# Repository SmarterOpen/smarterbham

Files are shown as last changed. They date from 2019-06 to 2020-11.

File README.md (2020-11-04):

# SmarterBham
The SmarterBham project
Imagine a city driven by information.  A place where decision making is supported by a city-wide sensor network that provides real time data about the state of things.  Imagine the platform that runs the network, built and owned by the citizens, measuring the things that we think are important and giving us the insights we need to make our city the best it can be. The SmarterBham project was born out of a recognition that smart cities need grassroots participation. We can combine open hardware designs with open networks, open platforms and open data policies to build a participatory smart cities future.

# Project Structure
* /lopy4 - all the code that runs on the device
* /doc - our documentation.  Requirements, wireframes, flow, security audits, etc
* /web - the web application that we use to manage devices, users, and to analyze collected data

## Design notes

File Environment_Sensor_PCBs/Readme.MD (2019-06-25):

Created in Eagle 9.4
zip files contain Gerber files formatted for OSHPARK or similar.
10 unit buy has BOM from Mouser for all the parts used.  
Dust sensor was $10 cheaper each unit at newark, even after shipping.. so shop around

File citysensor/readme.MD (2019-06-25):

The contents of this folder are hereby deprecated.  We abandoned using a Raspi Zero W and moved to Pycom LoPy4 instead
This branch never went further than building a prototype PCB.

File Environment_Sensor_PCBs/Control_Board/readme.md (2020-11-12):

This folder will house the Control Board design filse

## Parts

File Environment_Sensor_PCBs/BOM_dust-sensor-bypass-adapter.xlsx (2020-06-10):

Part | Value | Part Number | Device | Package | Library | Sheet
C1 | 100nF | CC0603KRX7R8BB104 | CAP_NP_0603 | SMD_0603 | daneagle_db8.0 | 1
C2 | 2.2uF | 1206B225K160CT | CAP_NP_1206 | SMD_1206 | daneagle_db8.0 | 1
CON1 | 53261-0471 | 53261-0471 | 53261-0471 | 53261-04 | con-molex | 1
SOM1a | hdr-1x14 | 801-87-014-53-001101 | 1x14 socket adapter wire wrap | PYCOM_LOPY4_PTH | daneagle_db8.0 | 1
SOM1b | hdr-1x14 | 801-87-014-53-001101 | 1x14 socket adapter wire wrap | PYCOM_LOPY4_PTH | daneagle_db8.0 | 1
U2 | MIC9409x | MIC94091YC6-TR | MIC9409X-MICREL-HIGH-SIDE-LOAD-SW_SC70(C6) | SC-70(C6) | daneagle_db8.0 | 1

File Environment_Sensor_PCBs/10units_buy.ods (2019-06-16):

Qty | Value | Device | Package | Parts | Description | MF | Mouser PN | OC_FARNELL | OC_NEWARK
7 | 0.1uF | CAP_NP_0402 | SMD_0402 | C1, C3, C7
1 | 0r | RESISTOR_0603 | SMD_0603 | R0X76
4 | 100nF | CAP_NP_0603 | SMD_0603 | C1, C2
5 | 10uF | CAP_POL_SMD_1206 | CAP_POL_1206 | C3
1 | 1k | RESISTOR_0603 | SMD_0603 | R5
2 | 1k7 | RESISTOR_0603 | SMD_0603 | R1, R2
2 | 1k8 | RESISTOR_0402 | SMD_0402 | R1, R2
1 | 22k1 | RESISTOR_0603 | SMD_0603 | R6 |  |  | 603-RC0603FR-0722K1L
1 | 22uf | CAP_NP_0603 | SMD_0603 | C1
2 | 270k | RESISTOR_0402 | SMD_0402 | R1, R8
1 | 2A | FUSE_CLIP_SMD_AUTO_MINI_LOWPROF | FUSE_SMD_AUTO_MINI_LOWPROF | F1 |  |  | 576-0891002.H
1 | Holder | FUSE_CLIP_SMD_AUTO_MINI_LOWPROF | FUSE_SMD_AUTO_MINI_LOWPROF | F1 |  |  | 534-3587
2 | 2k2 | RESISTOR_0402 | SMD_0402 | R2, R3
1 | 330r | RESISTOR_0603 | SMD_0603 | R4
1 | 4.7uf | CAP_NP_0603 | SMD_0603 | C9
4 | 47k | RESISTOR_0402 | SMD_0402 | R4, R5, R6, R7
1 | 47k | RESISTOR_ARRAY_4X | SMD_4X_0603 | RA1
1 | 47k5 | RESISTOR_0603 | SMD_0603 | R7 |  |  | 603-RC0603FR-0747K5L
2 | 4k7 | RESISTOR_0603 | SMD_0603 | R1, R2
7 | 53261-04 | 53261-04 | 53261-04 | IN, OUT | CONNECTOR | MOLEX | 538-53261-0471 | 1125374 | unknown
2 | 53398-05 | 53398-05 | 53398-05 | X3, X4 | CONNECTOR | MOLEX | 538-53261-0571 | 1125354 | unknown
3 | 90R | RESISTOR_0603 | SMD_0603 | R3, R8, R9
1 | BME680_GAS_AQ/BARO/TEMP/HUMID-I2C-SPI | BME680_GAS_AQ/BARO/TEMP/HUMID-I2C-SPI | BOSCH_LGA8 | U1
1 | CP2012N-A01-GQFN20R | CP2012N-A01-GQFN20R | QFN20 | U2 |  |  | 634-CP2102NA01GQFN20
5 | EVPAA | SWITCH_MOM_PANA_EVPAA_3.5X2.9 | EVPAA_SWITCH | SW1, SW2, SW3, SW4, SW5
1 | GUVA_C32SM | GUVA_C32SM_OLGA | 2X2.3OLGA | U2
1 | GUVb_C31SM | GUVA_C32SM_OLGA | 2X2.3OLGA | U3
2 | LED_SMD_0603 | LED_SMD_0603 | LED_SMD_0603 |  |  |  | 743-IN-S63AT5G
2 | LED_SMD_0603 | LED_SMD_0603 | LED_SMD_0603 | D1, D2, D3, D4 |  |  | 743-S63BTR
1 | LM2596S_MOD_5.5VOUT | LM2596S-BUCK_CVTR-MODULE | LM2596S_MODULE | MOD1
1 | NCP1117_SOT-223-4 | NCP1117_SOT-223-4 | SOT-223 | U1
1 | SI1151_AB00_DFN10 | SI1151_AB00_DFN10 | QFN10 | U1 |  |  | 634-SI1132-A10-GMR
1 | USB | USB | USB_MICRO_B_SMD_AMPHENOL | CON1 |  |  | 649-10118193-0001LF
1 | USB_ESD-TVS_NUF2101MT1G | USB_ESD-TVS_NUF2101MT1G | TSOP-6 | U3 |  |  | 863-NUF2101MT1G
1 | VEML6070_OPLGA | VEML6070_OPLGA | OPLGA-6 | U2
1 |  | P-RJLSE-4X381-01_AMPHENOL | P-RJLSE-4X381-01_AMPHENOL_SMD_RJ45 | CON2 |  |  | 523-RJLSE4138101
1 |  | PYCOM_LOPY4PTH | PYCOM_LOPY4_PTH | SOM1 |  |  | 365-LOPY4
2 |  |  | socket 1x14 loprofile | SOM1 |  |  | 517-929870-01-14-RA
1 |  | Wifi Antenna Kit | WIFI Antenna Kit |  |  |  | 474-WRL-14676
1 |  | hpma115s0 dust sensor |  | x3

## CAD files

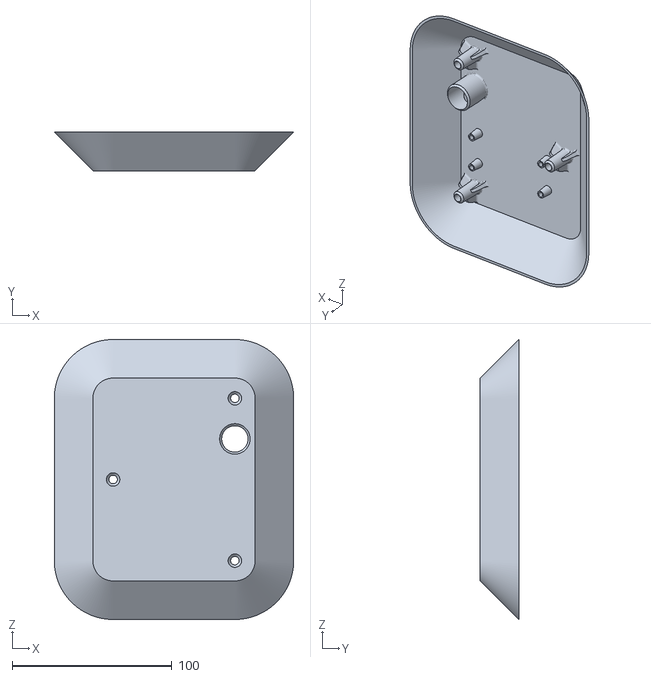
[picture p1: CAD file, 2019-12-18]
Environment_Sensor_PCBs/Louver_L4_v2.stl
149.9 x 24.1 x 175.3

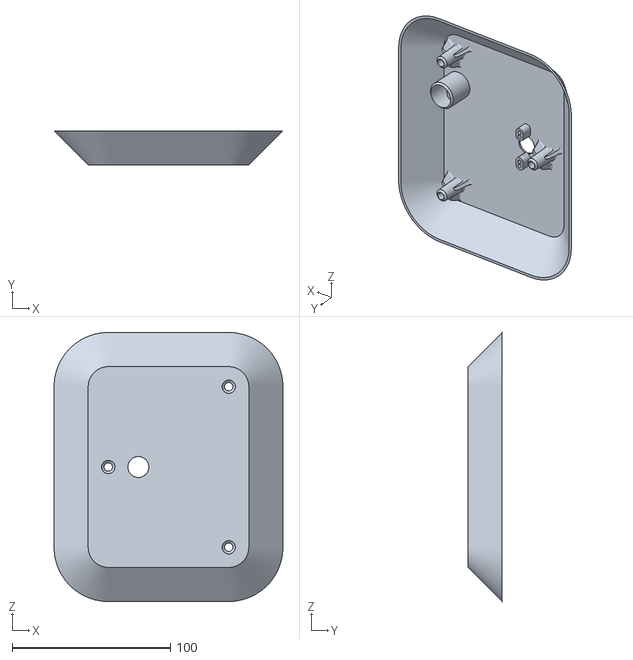
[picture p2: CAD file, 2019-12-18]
Environment_Sensor_PCBs/Louver_Top.v2.stl
144.8 x 21.6 x 170.2

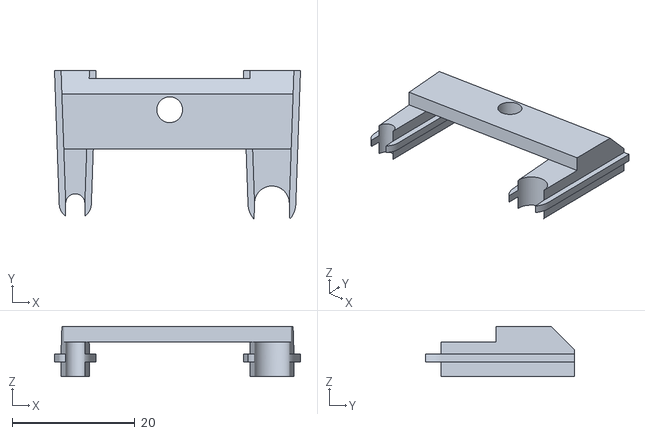
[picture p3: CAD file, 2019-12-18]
Environment_Sensor_PCBs/cable_grip_base.v2.stl
40.0 x 24.2 x 8.19

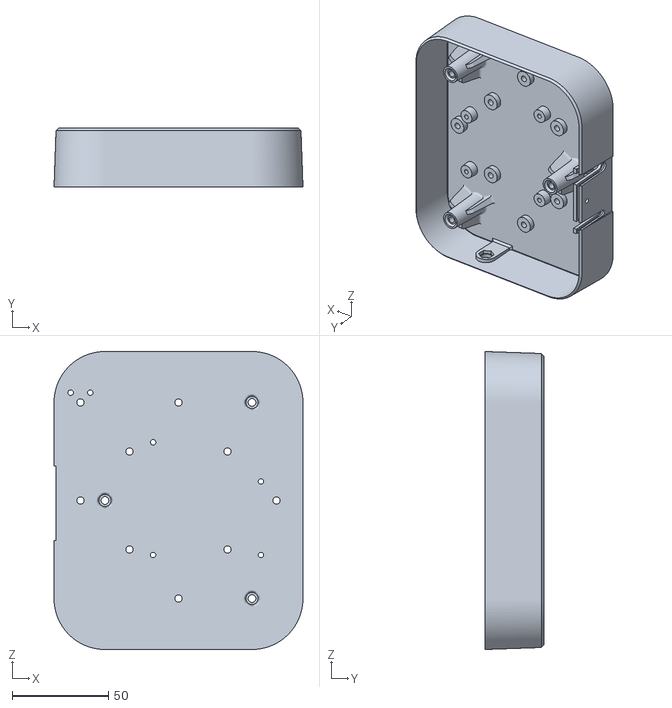
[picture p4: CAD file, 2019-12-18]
Environment_Sensor_PCBs/Base_pycom.v3.stl
129.0 x 30.5 x 154.4

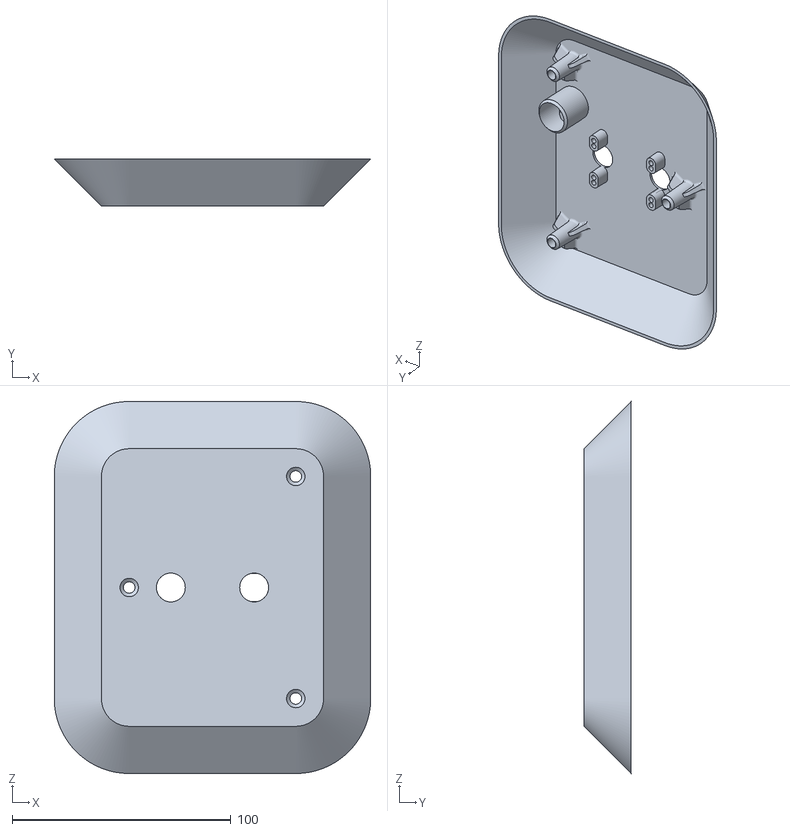
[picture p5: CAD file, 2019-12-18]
Environment_Sensor_PCBs/Louver_Top_2LS.stl
144.8 x 21.6 x 170.2

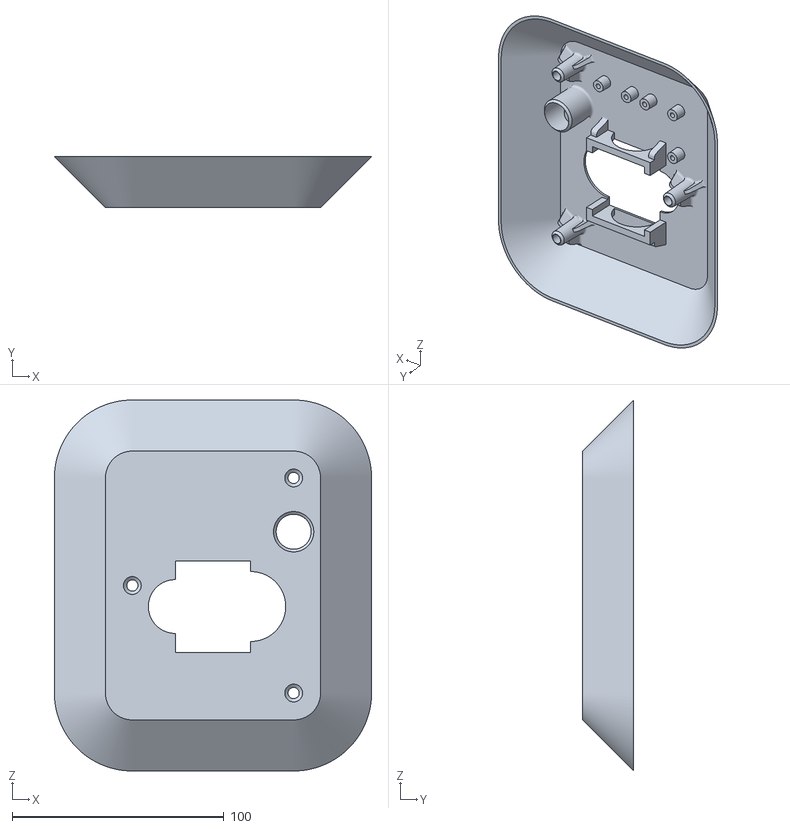
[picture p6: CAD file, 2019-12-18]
Environment_Sensor_PCBs/Louver_HPMA.v2.stl
149.9 x 24.1 x 175.3

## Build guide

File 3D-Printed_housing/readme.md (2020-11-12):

This location will house the 3D printed parts

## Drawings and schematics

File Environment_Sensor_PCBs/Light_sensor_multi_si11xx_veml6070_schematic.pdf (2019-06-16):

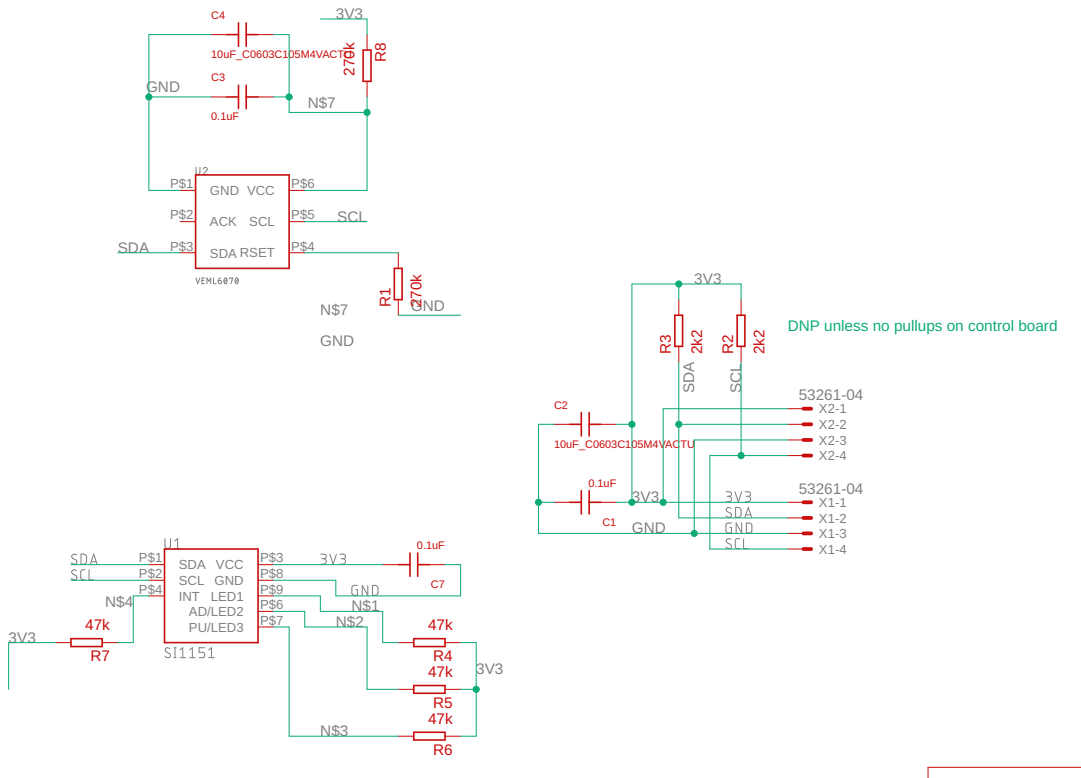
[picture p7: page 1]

DNP unless no pullups on control board

Document Number: | REV:

Date: 6/16/19 6:17 AM | Sheet: 1/1

6/16/19 6:18 AM f=0.89 /home/space/Dropbox/Eagle_8.0/projects/Environment_Sensor_system/Light_sensor_multi_si11xx_veml6070.sch (Sheet: 1/1)

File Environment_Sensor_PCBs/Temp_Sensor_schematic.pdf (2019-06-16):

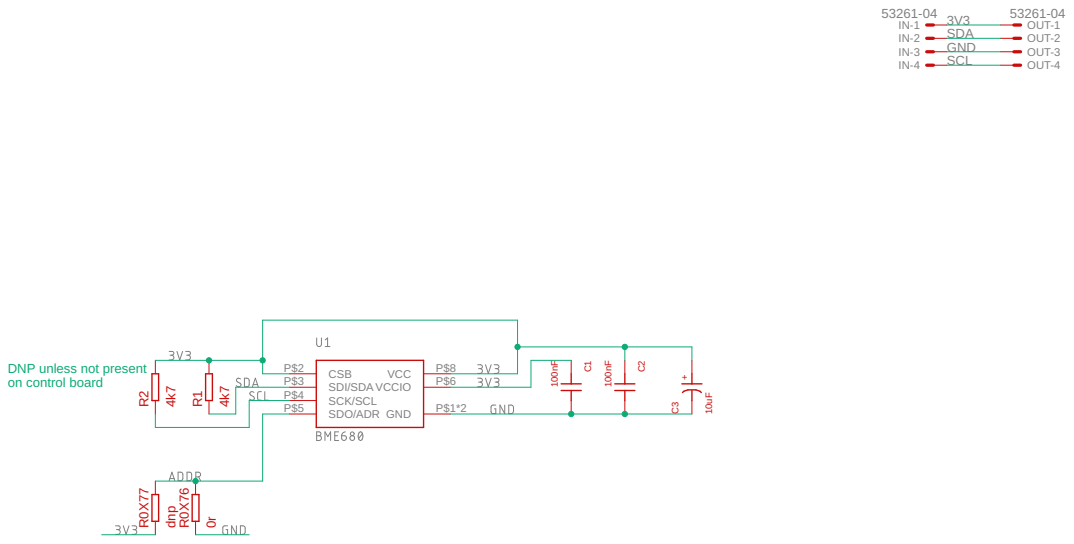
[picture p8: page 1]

DNP unless not present on control board

Document Number: | REV:

Date: 6/16/19 6:20 AM | Sheet: 1/1

6/16/19 6:21 AM f=0.89 /home/space/Dropbox/Eagle_8.0/projects/Environment_Sensor_system/Temp_Sensor.sch (Sheet: 1/1)

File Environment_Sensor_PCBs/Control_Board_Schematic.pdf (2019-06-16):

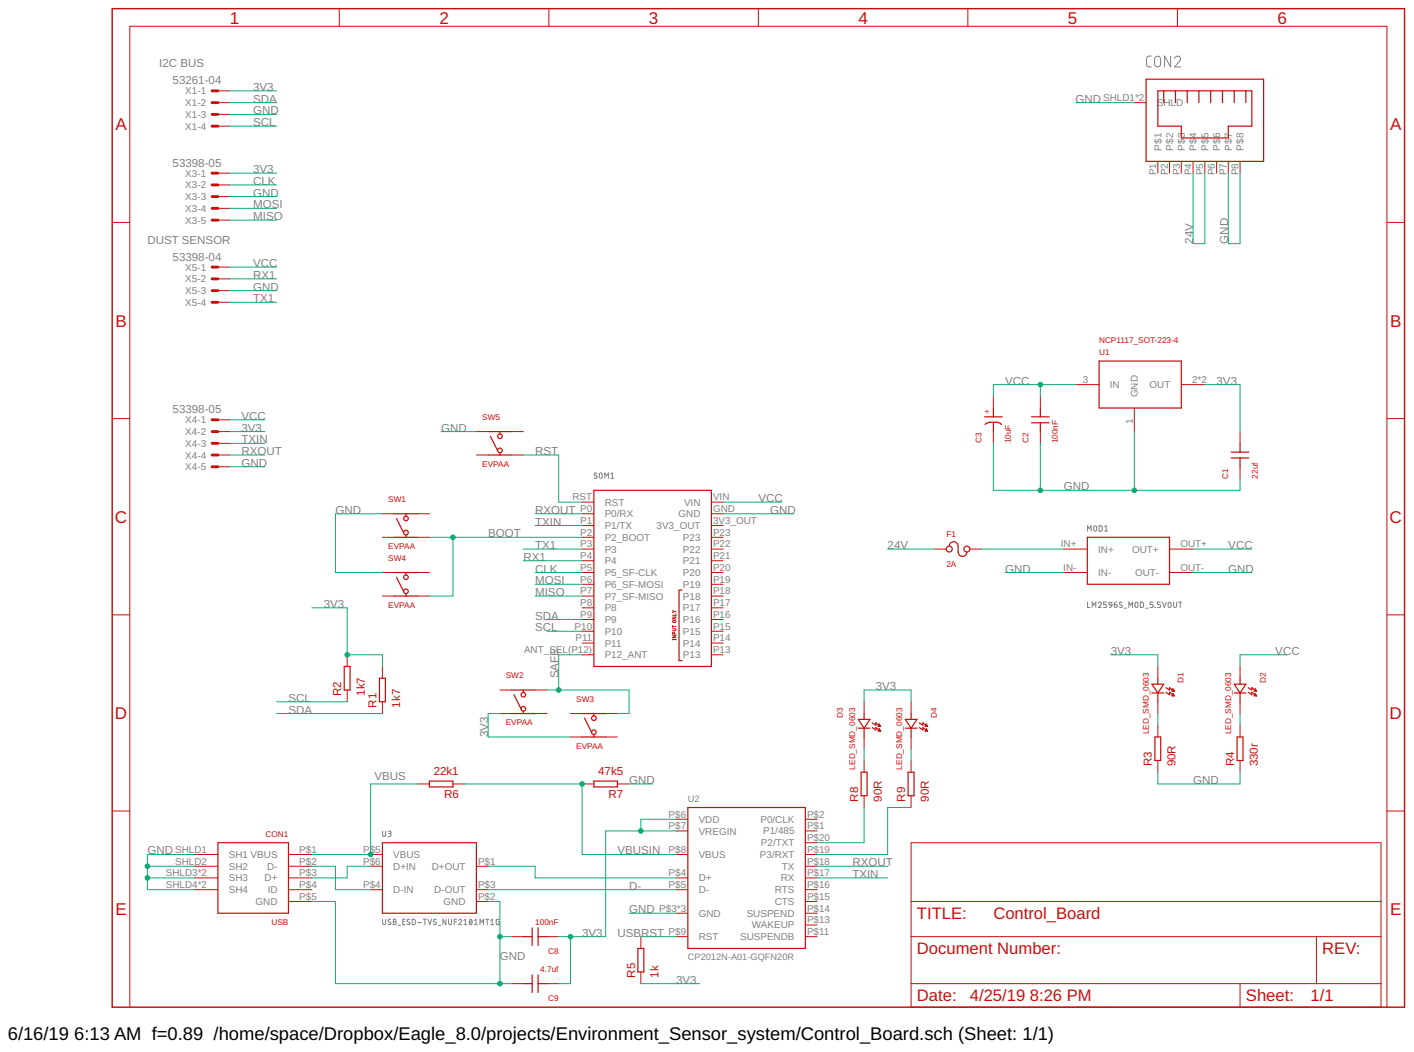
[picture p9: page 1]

6/16/19 6:13 AM f=0.89 /home/space/Dropbox/Eagle_8.0/projects/Environment_Sensor_system/Control_Board.sch (Sheet: 1/1)

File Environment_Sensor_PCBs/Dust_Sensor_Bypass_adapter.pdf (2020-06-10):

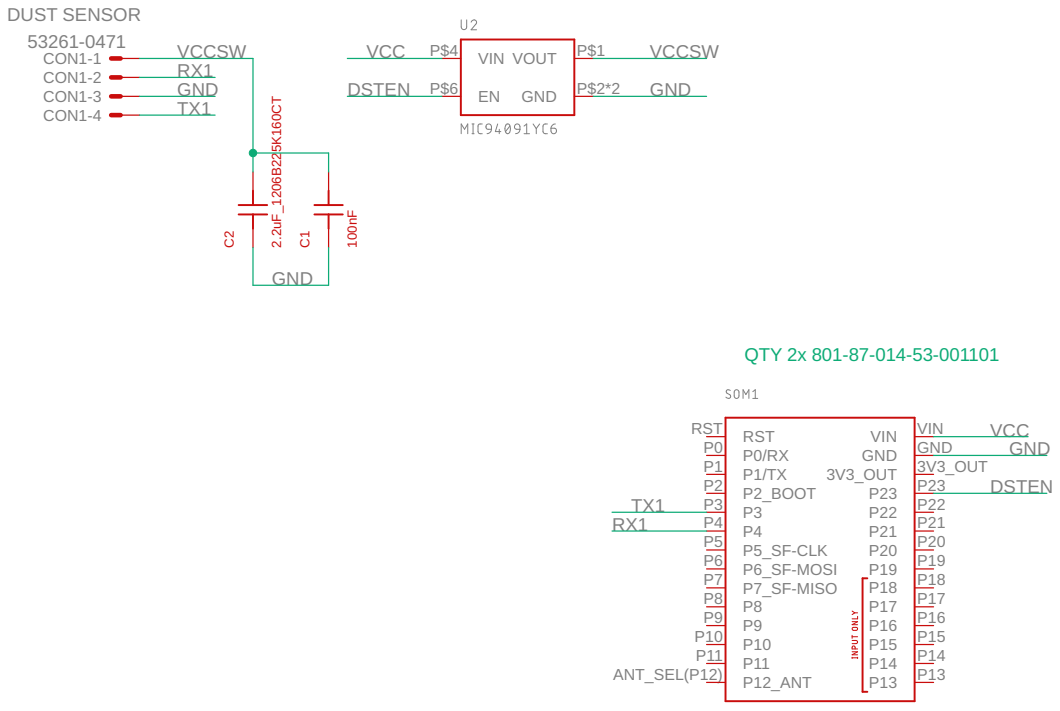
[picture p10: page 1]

Document Number: | REV:

Date: 5/27/2020 4:20 PM | Sheet: 1/1

6/9/2020 8:57 PM f=0.89 D:\Dropbox\Eagle_8.0\projects\Environment_Sensor_system\Dust_Sensor_Bypass_adapter.sch (Sheet: 1/1)

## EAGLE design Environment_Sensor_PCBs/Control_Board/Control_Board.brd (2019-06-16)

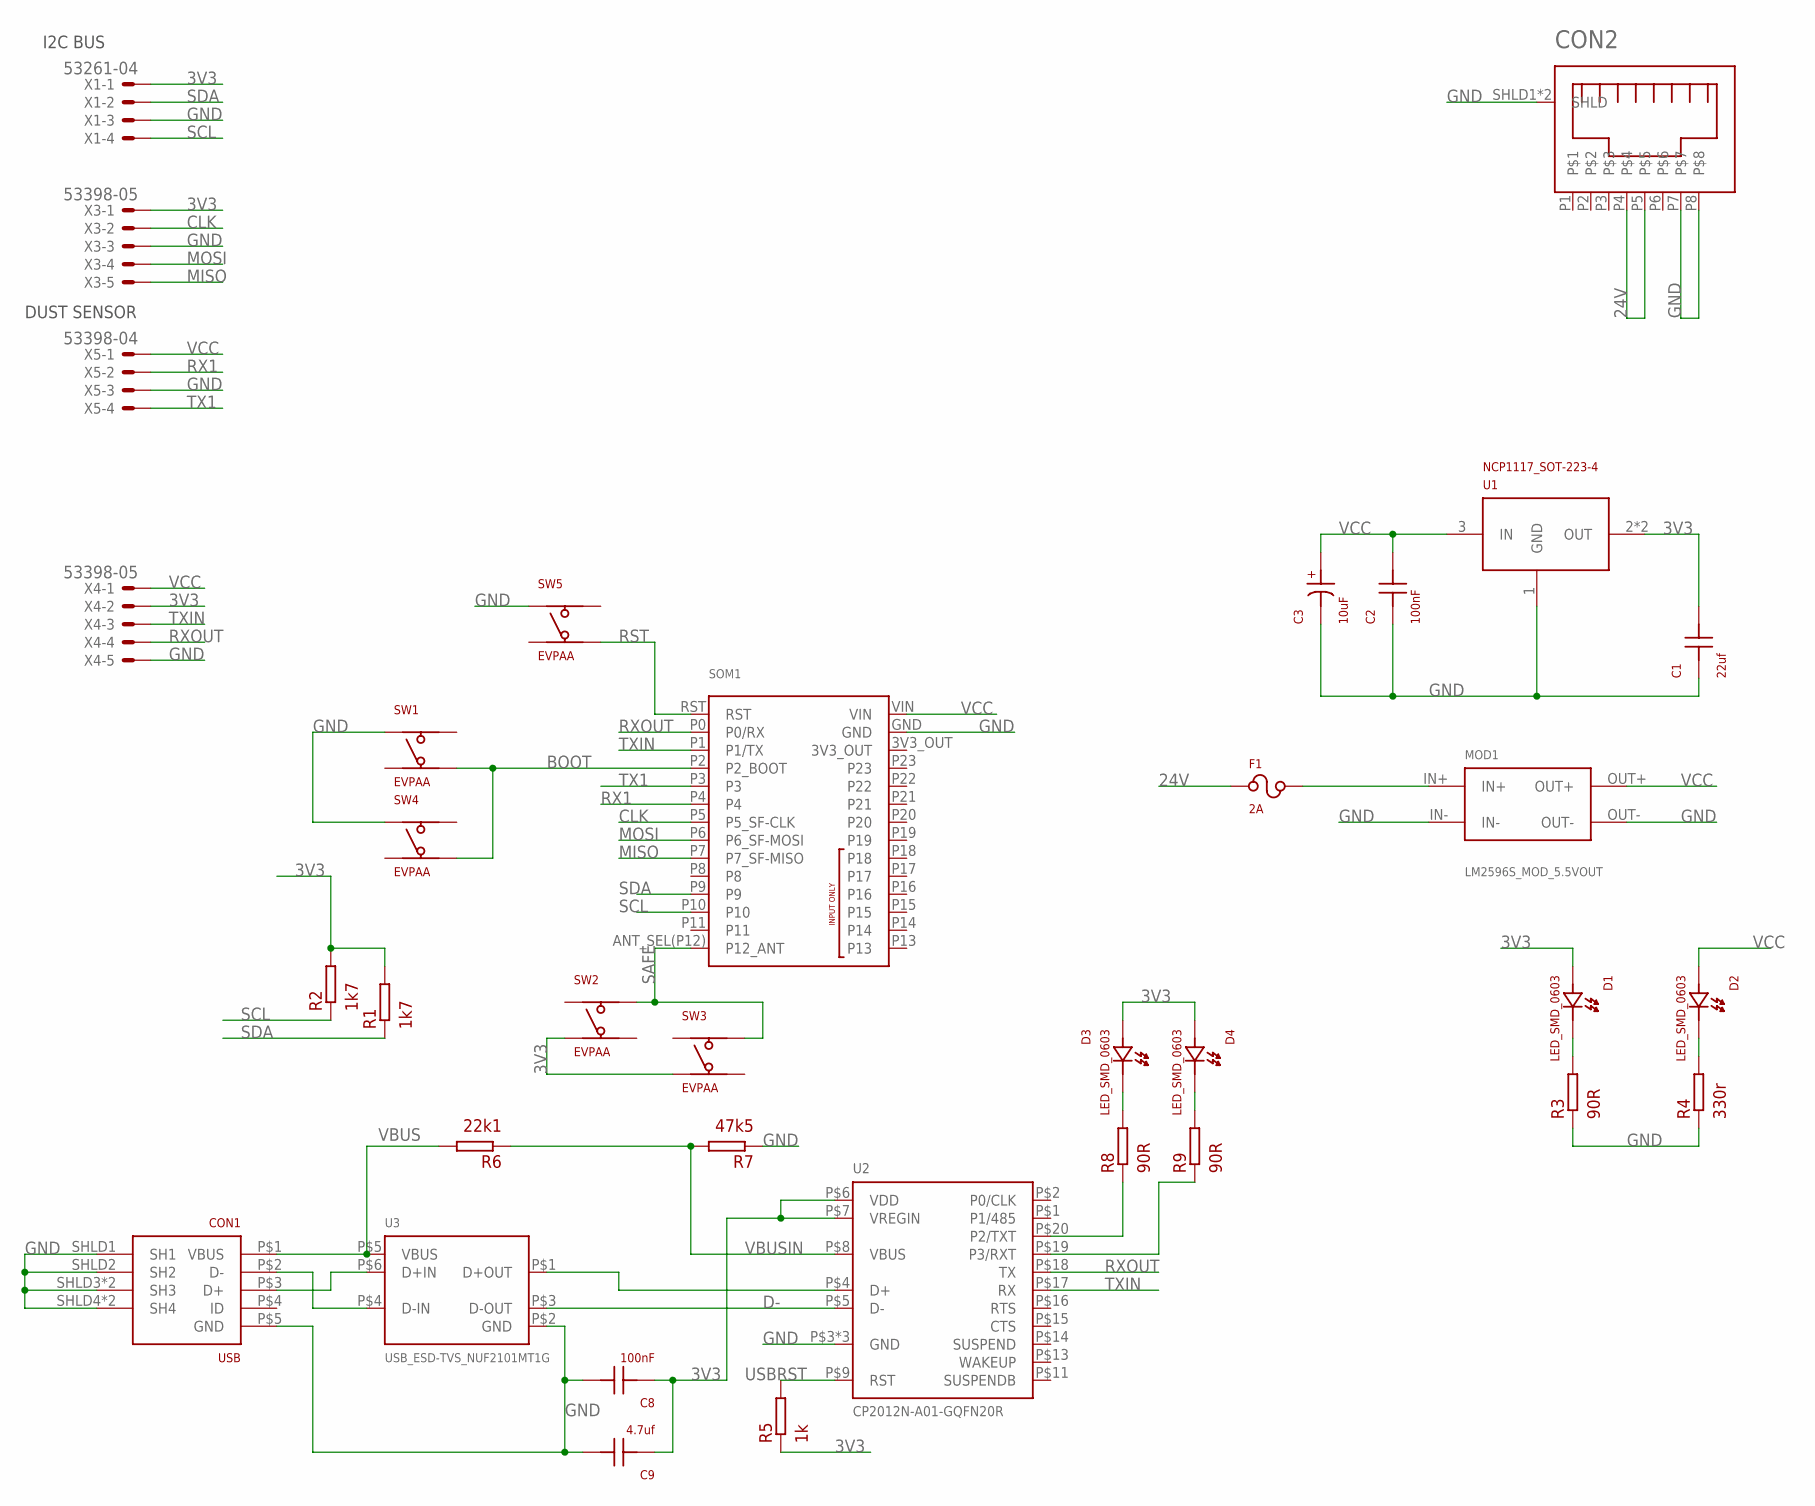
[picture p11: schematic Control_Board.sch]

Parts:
C1: 22uf; SMD_0603
C2, C8: 100nF; SMD_0603
C3: 10uF; CAP_POL_1206
C9: 4.7uf; SMD_0603
CON1: USB; USB_MICRO_B_SMD_AMPHENOL
CON2: P-RJLSE-4X381-01_AMPHENOL; P-RJLSE-4X381-01_AMPHENOL_SMD_RJ45
D1, D2, D3, D4: LED_SMD_0603
F1: 2A; FUSE_SMD_AUTO_MINI_LOWPROF
MOD1: LM2596S_MOD_5.5VOUT; LM2596S_MODULE
R1, R2: 1k7; SMD_0603
R3, R8, R9: 90R; SMD_0603
R4: 330r; SMD_0603
R5: 1k; SMD_0603
R6: 22k1; SMD_0603
R7: 47k5; SMD_0603
SOM1: PYCOM_LOPY4PTH; PYCOM_LOPY4_PTH
SW1, SW2, SW3, SW4, SW5: EVPAA; EVPAA_SWITCH
U1: NCP1117_SOT-223-4; SOT-223
U2: CP2012N-A01-GQFN20R; QFN20
U3: USB_ESD-TVS_NUF2101MT1G; TSOP-6
X1: 53261-04
X3, X4: 53398-05
X5: 53398-04

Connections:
3V3: C1.P$2, C8.P$1, C9.P$1, D1.A, D3.A, D4.A, R1.P$2, R2.P$2, R5.P$1, SW2.P$1 (A1), SW3.P$1 (A1), U1.2 (OUT), U1.4 (OUT), U2.P$6 (VDD), U2.P$7 (VREGIN), X1.1, X3.1, X4.2
3V3_OUT: SOM1.3V3_OUT
24V: CON2.P4, CON2.P5, F1.P1A, F1.P1B
BOOT: SOM1.P2 (P2_BOOT), SW1.P$1' (A2), SW4.P$1' (A2)
CLK: SOM1.P5 (P5_SF-CLK), X3.2
D-: U2.P$5 (D-), U3.P$3 (D-OUT)
GND: C1.P$1, C2.P$1, C3.N, C8.P$2, C9.P$2, CON1.P$5 (GND), CON1.SHLD1 (SH1), CON1.SHLD2 (SH2), CON1.SHLD3 (SH3), CON1.SHLD4 (SH4), CON1.SHLD5 (SH3), CON1.SHLD6 (SH4), CON2.P7, CON2.P8, CON2.SHLD1 (SHLD), CON2.SHLD2 (SHLD), MOD1.IN-, MOD1.OUT-, R3.P$1, R4.P$1, R7.P$1, SOM1.GND, SW1.P$2 (B1), SW4.P$2 (B1), SW5.P$2 (B1), U1.1 (GND), U2.P$3 (GND), U2.P$12 (GND), U2.PAD (GND), U3.P$2 (GND), X1.3, X3.3, X4.5, X5.3
MISO: SOM1.P7 (P7_SF-MISO), X3.5
MOSI: SOM1.P6 (P6_SF-MOSI), X3.4
unnamed: F1.P2A, F1.P2B, MOD1.IN+
unnamed: CON1.P$3 (D+), U3.P$6 (D+IN)
unnamed: U2.P$4 (D+), U3.P$1 (D+OUT)
unnamed: CON1.P$2 (D-), U3.P$4 (D-IN)
unnamed: D3.K, R8.P$2
unnamed: D4.K, R9.P$2
unnamed: R9.P$1, U2.P$19 (P3/RXT)
unnamed: R8.P$1, U2.P$20 (P2/TXT)
unnamed: D1.K, R3.P$2
unnamed: D2.K, R4.P$2
RST: SOM1.RST, SW5.P$1' (A2)
RX1: SOM1.P4, X5.2
RXOUT: SOM1.P0 (P0/RX), U2.P$18 (TX), X4.4
SAFE: SOM1.ANT_SEL(P12) (P12_ANT), SW2.P$2' (B2), SW3.P$2' (B2)
SCL: R2.P$1, SOM1.P10, X1.4
SDA: R1.P$1, SOM1.P9, X1.2
TX1: SOM1.P3, X5.4
TXIN: SOM1.P1 (P1/TX), U2.P$17 (RX), X4.3
USBRST: R5.P$2, U2.P$9 (RST)
VBUS: CON1.P$1 (VBUS), R6.P$2, U3.P$5 (VBUS)
VBUSIN: R6.P$1, R7.P$2, U2.P$8 (VBUS)
VCC: C2.P$2, C3.P, D2.A, MOD1.OUT+, SOM1.VIN, U1.3 (IN), X4.1, X5.1

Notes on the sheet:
DUST SENSOR
I2C BUS

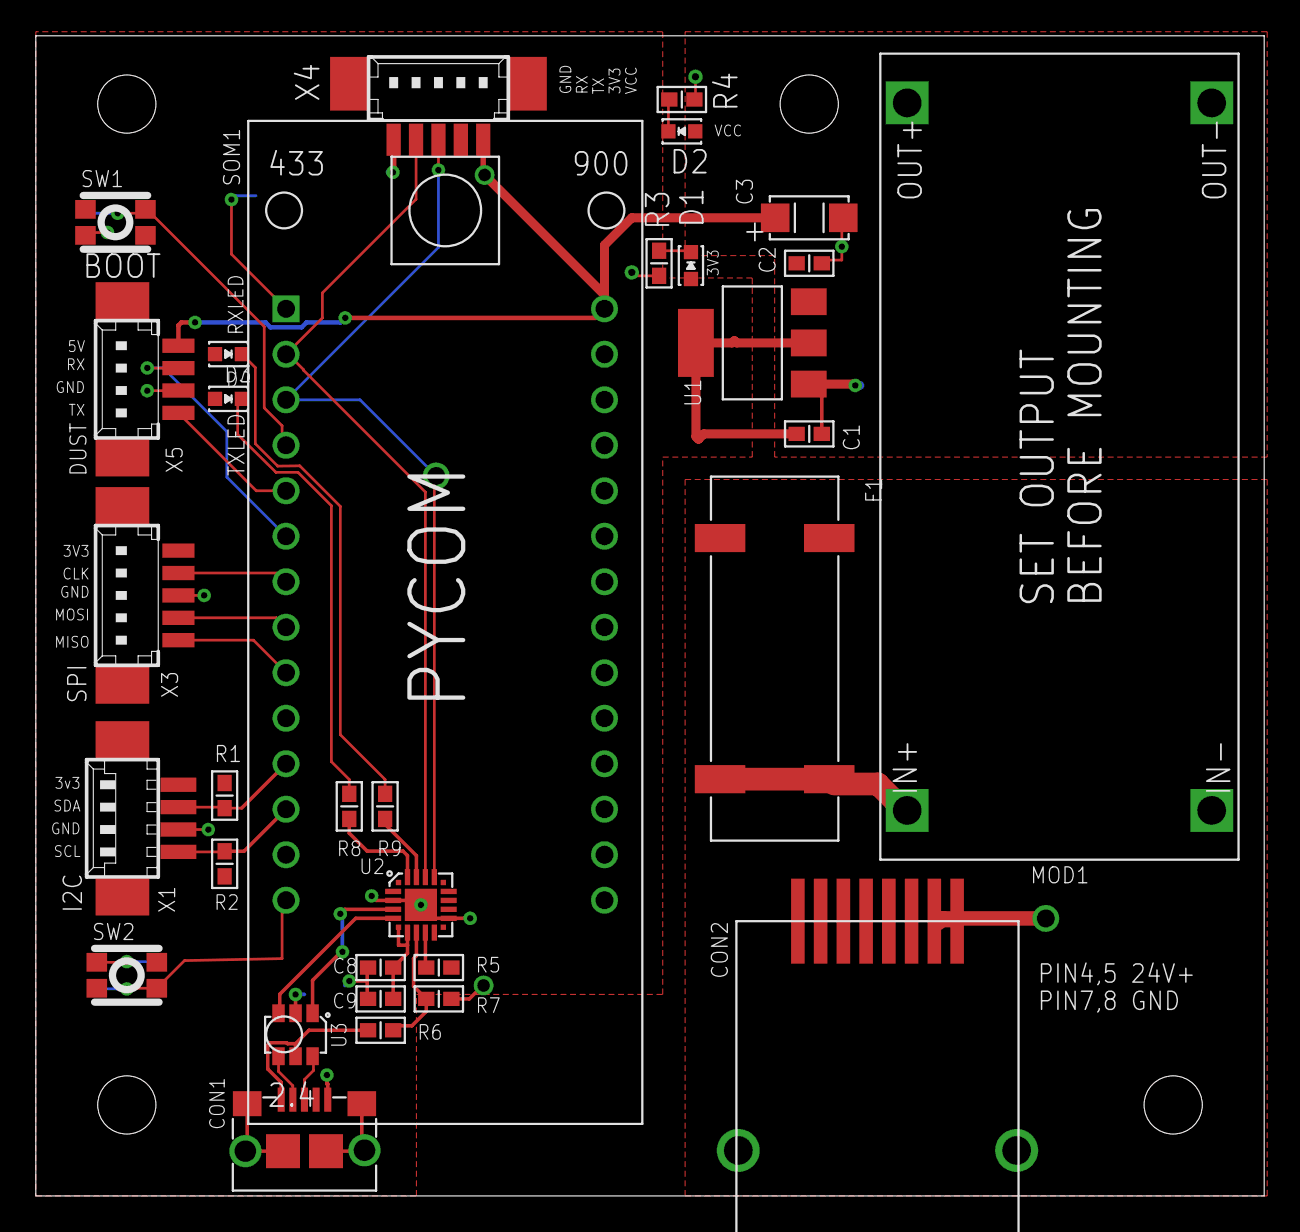
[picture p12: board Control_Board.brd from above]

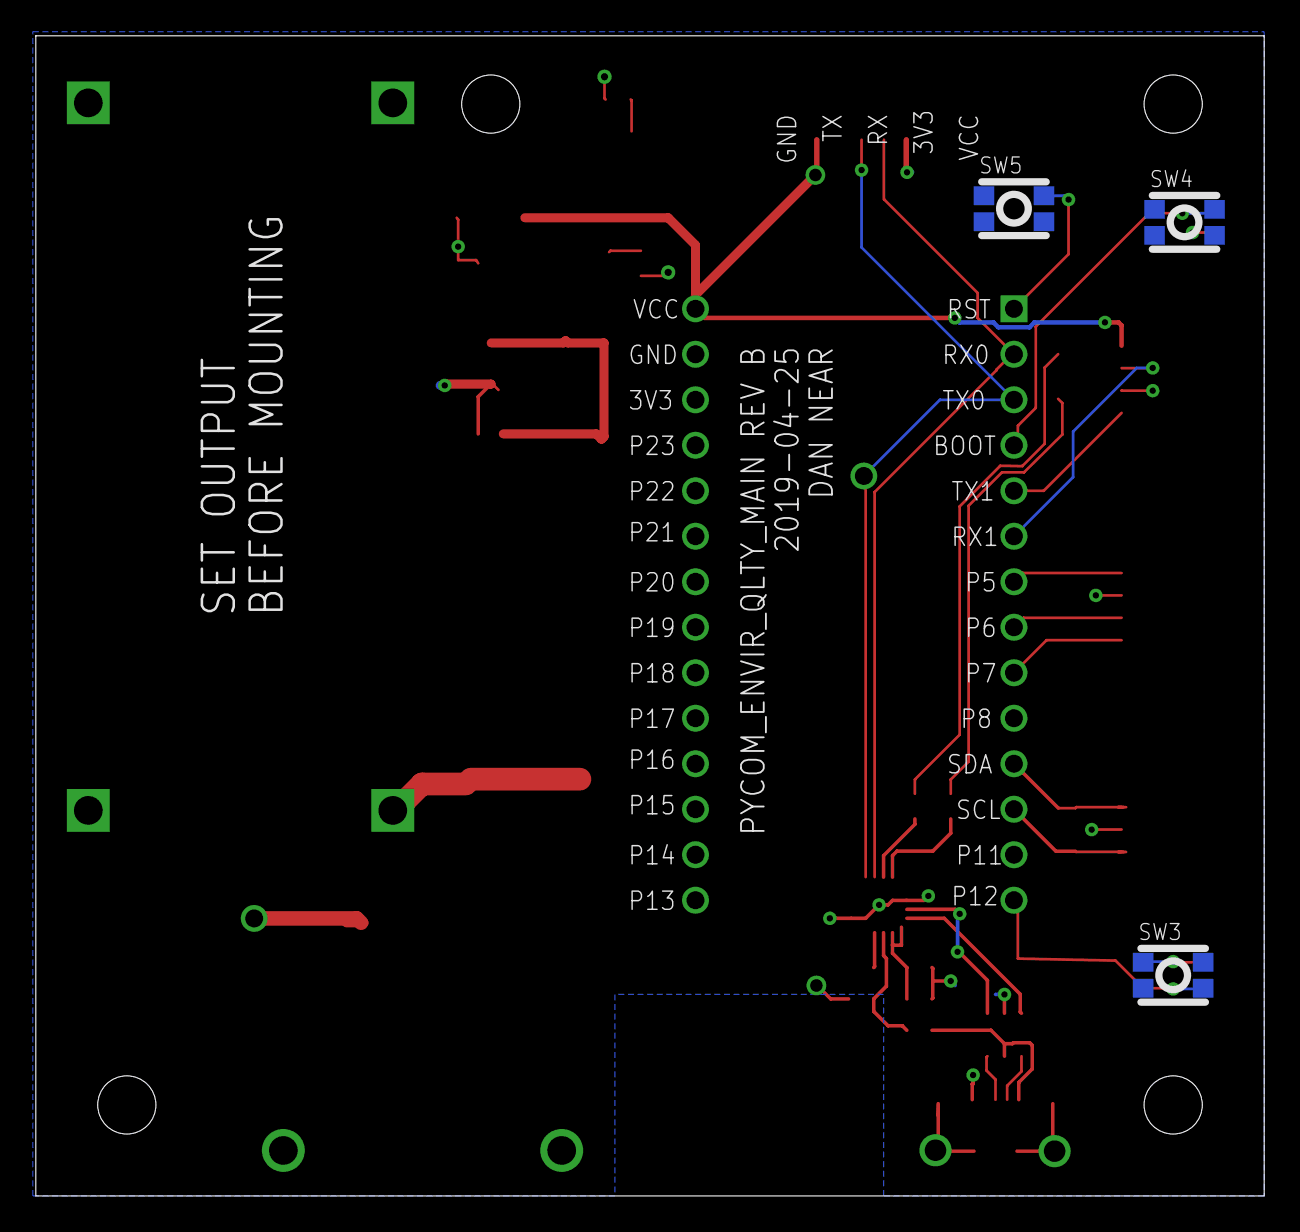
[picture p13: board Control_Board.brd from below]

Board: 2 copper layers, 68.6 x 64.8 mm, 35 parts (3 on the bottom side), 30 nets.

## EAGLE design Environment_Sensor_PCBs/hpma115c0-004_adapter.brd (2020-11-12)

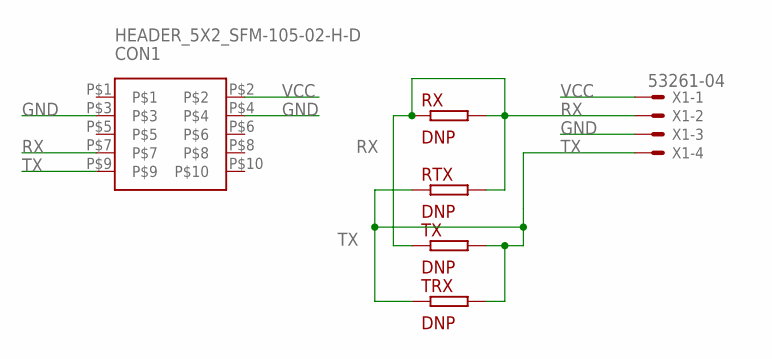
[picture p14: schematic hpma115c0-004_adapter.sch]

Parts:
CON1: HEADER_5X2_SFM-105-02-H-D; HEADER_5X2_1.27X1.27_SMD_SAMTEK
RTX: DNP; SMD_0402
RX: DNP; SMD_0402
TRX: DNP; SMD_0402
TX: DNP; SMD_0402
X1: 53261-04

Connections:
GND: CON1.P$3, CON1.P$4, X1.3
RX: CON1.P$7, RTX.P$2, RX.P$1, RX.P$2, TX.P$1, X1.2
TX: CON1.P$9, RTX.P$1, TRX.P$1, TRX.P$2, TX.P$2, X1.4
VCC: CON1.P$2, X1.1

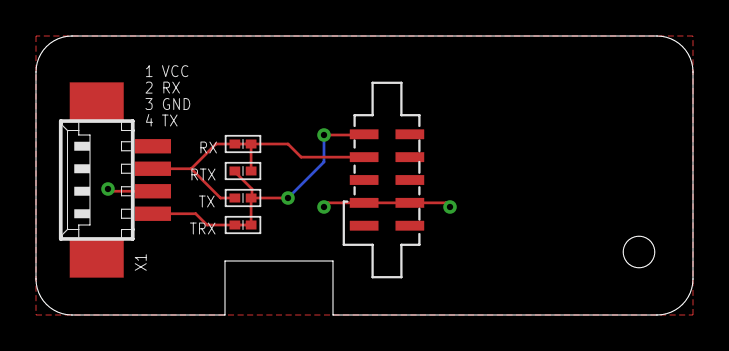
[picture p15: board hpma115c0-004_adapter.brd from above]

Board: 2 copper layers, 36.5 x 15.5 mm, 6 parts (0 on the bottom side), 4 nets.

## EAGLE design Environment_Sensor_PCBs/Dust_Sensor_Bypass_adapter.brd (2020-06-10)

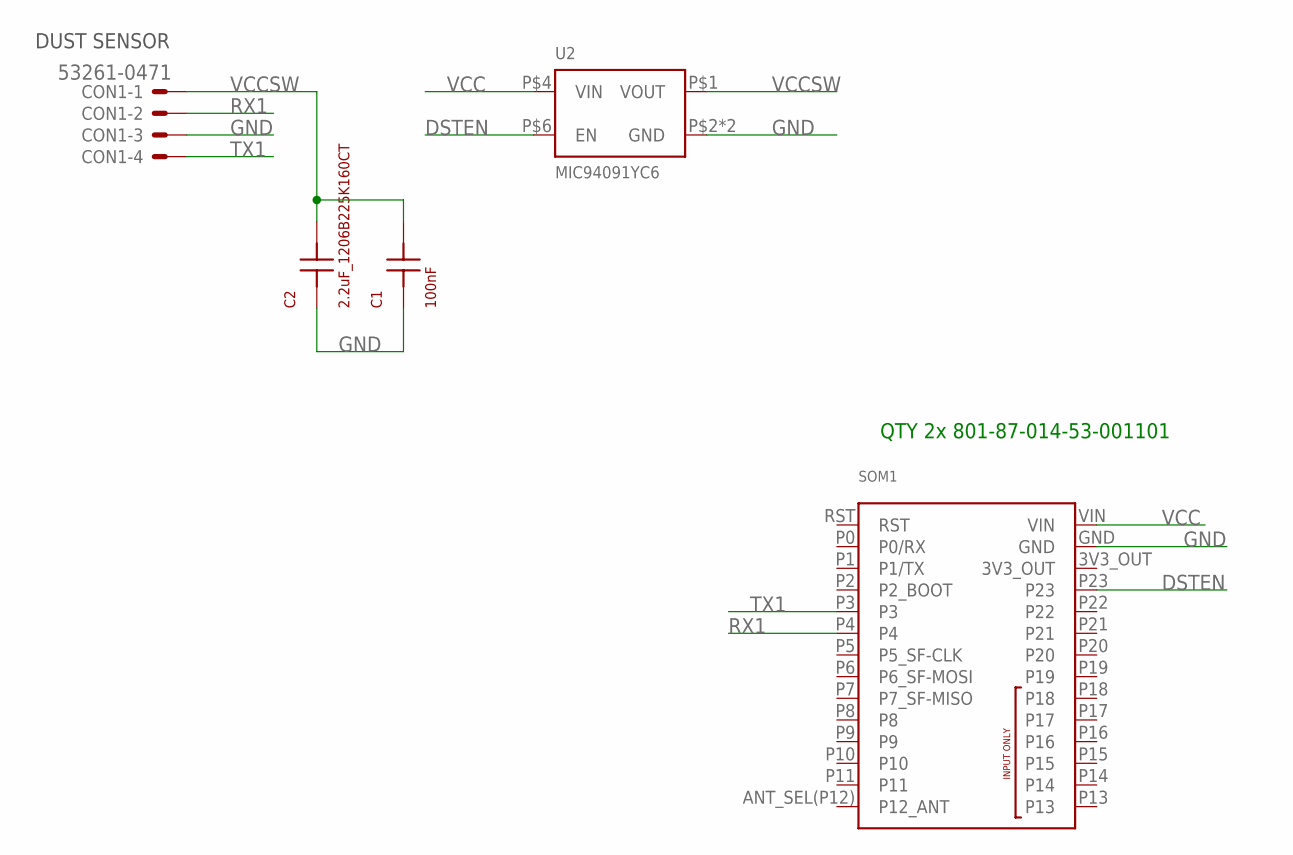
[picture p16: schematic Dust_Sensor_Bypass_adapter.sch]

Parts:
C1: 100nF; SMD_0603
C2: 2.2uF_1206B225K160CT; SMD_1206
CON1: 53261-0471; 53261-04
SOM1: PYCOM_LOPY4PTH; PYCOM_LOPY4_PTH
U2: MIC94091YC6; SC-70(C6)

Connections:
3V3_OUT: SOM1.3V3_OUT
DSTEN: SOM1.P23, U2.P$6 (EN)
GND: C1.P$1, C2.P$1, CON1.3, SOM1.GND, U2.P$2 (GND), U2.P$5 (GND)
RX1: CON1.2, SOM1.P4
TX1: CON1.4, SOM1.P3
VCC: SOM1.VIN, U2.P$4 (VIN)
VCCSW: C1.P$2, C2.P$2, CON1.1, U2.P$1 (VOUT)

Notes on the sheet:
DUST SENSOR
QTY 2x 801-87-014-53-001101

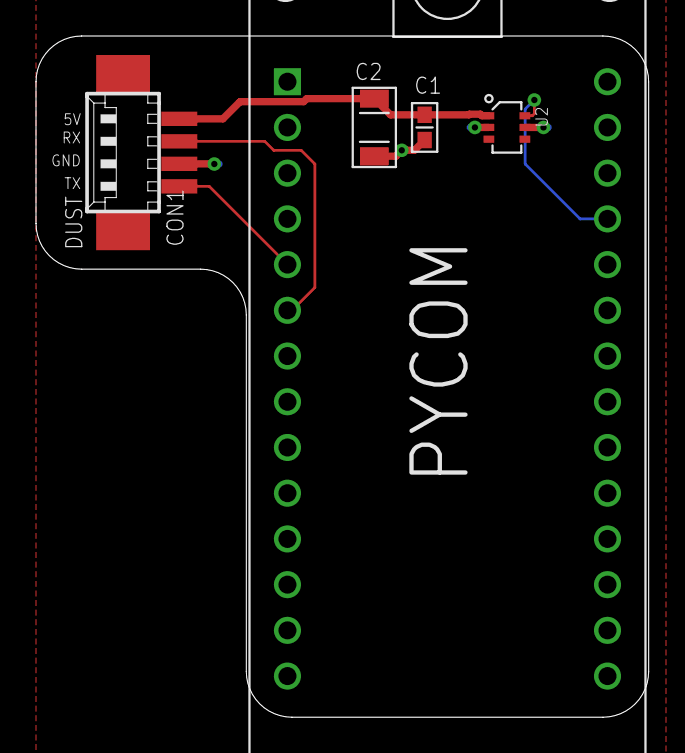
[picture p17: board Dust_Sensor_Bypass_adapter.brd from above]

Board: 2 copper layers, 34.0 x 37.8 mm, 5 parts (0 on the bottom side), 6 nets.

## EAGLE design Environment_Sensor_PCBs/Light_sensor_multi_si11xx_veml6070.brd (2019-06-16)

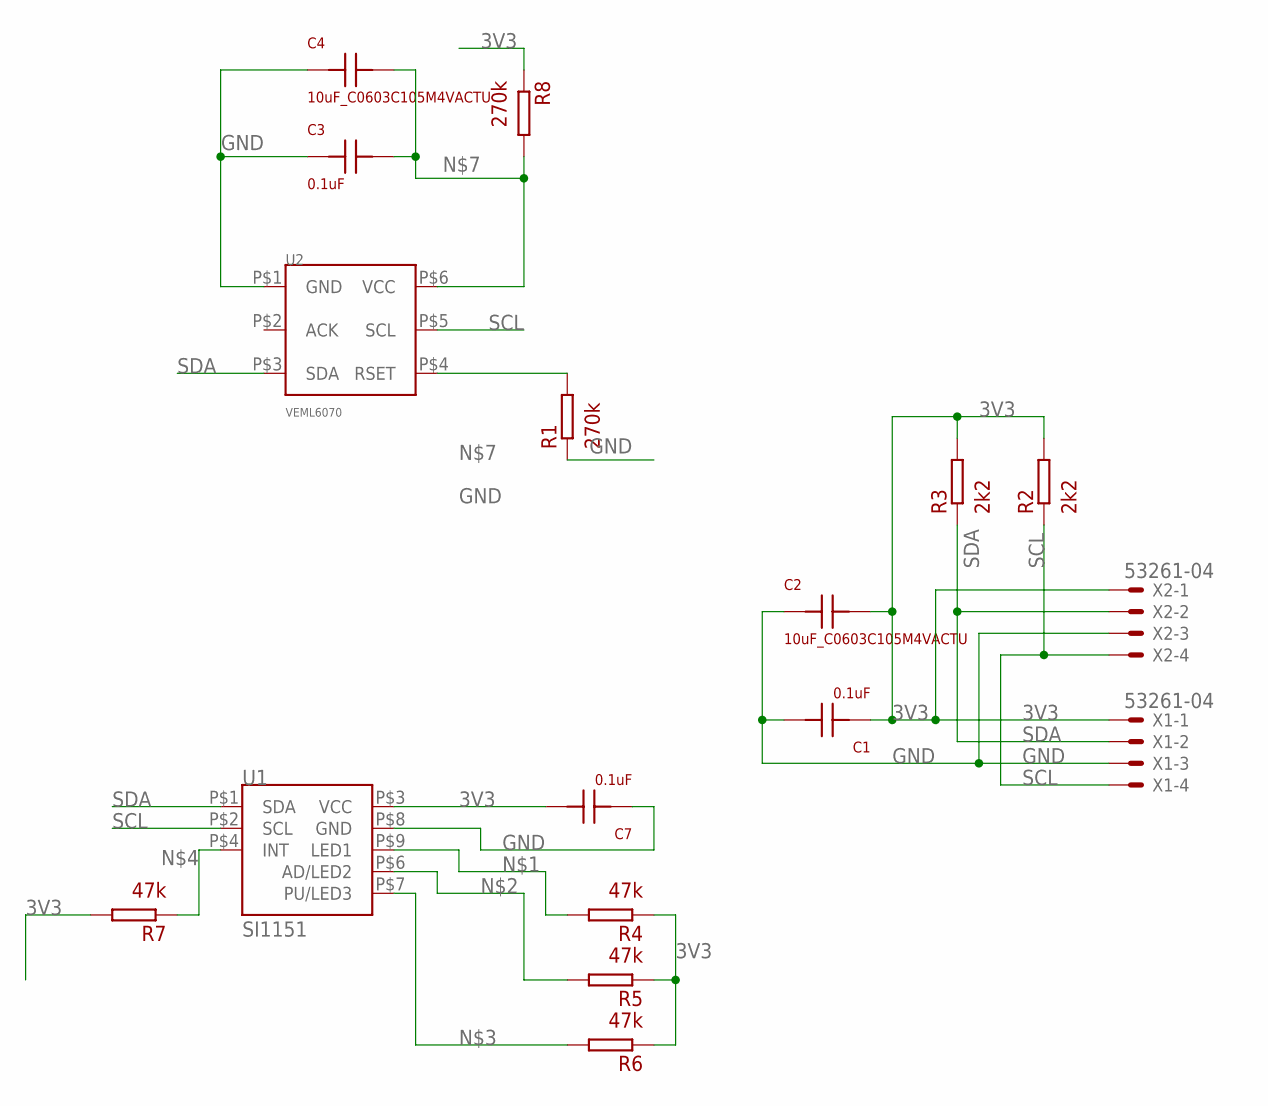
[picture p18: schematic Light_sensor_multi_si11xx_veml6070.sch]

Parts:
C1, C3, C7: 0.1uF; SMD_0402
C2, C4: 10uF_C0603C105M4VACTU; SMD_1206
R1, R8: 270k; SMD_0402
R2, R3: 2k2; SMD_0402
R4, R5, R6, R7: 47k; SMD_0402
U1: SI1151; QFN10
U2: VEML6070; OPLGA-6
X1, X2: 53261-04

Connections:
3V3: C1.P$1, C2.P$2, C7.P$2, R2.P$2, R3.P$2, R4.P$1, R5.P$1, R6.P$1, R7.P$2, R8.P$1, U1.P$3 (VCC), X1.1, X2.1
GND: C1.P$2, C2.P$1, C3.P$1, C4.P$1, C7.P$1, R1.P$1, U1.P$8 (GND), U2.P$1 (GND), X1.3, X2.3
unnamed: R4.P$2, U1.P$9 (LED1)
unnamed: R5.P$2, U1.P$6 (AD/LED2)
unnamed: R6.P$2, U1.P$7 (PU/LED3)
unnamed: R7.P$1, U1.P$4 (INT)
unnamed: R1.P$2, U2.P$4 (RSET)
unnamed: C3.P$2, C4.P$2, R8.P$2, U2.P$6 (VCC)
SCL: R2.P$1, U1.P$2 (SCL), U2.P$5 (SCL), X1.4, X2.4
SDA: R3.P$1, U1.P$1 (SDA), U2.P$3 (SDA), X1.2, X2.2

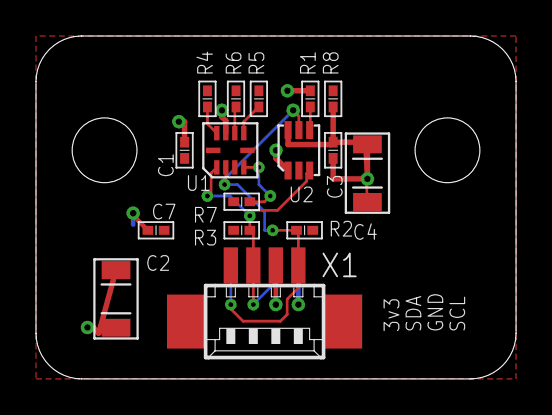
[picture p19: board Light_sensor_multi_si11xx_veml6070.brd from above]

Board: 2 copper layers, 26.7 x 19.1 mm, 17 parts (1 on the bottom side), 10 nets.

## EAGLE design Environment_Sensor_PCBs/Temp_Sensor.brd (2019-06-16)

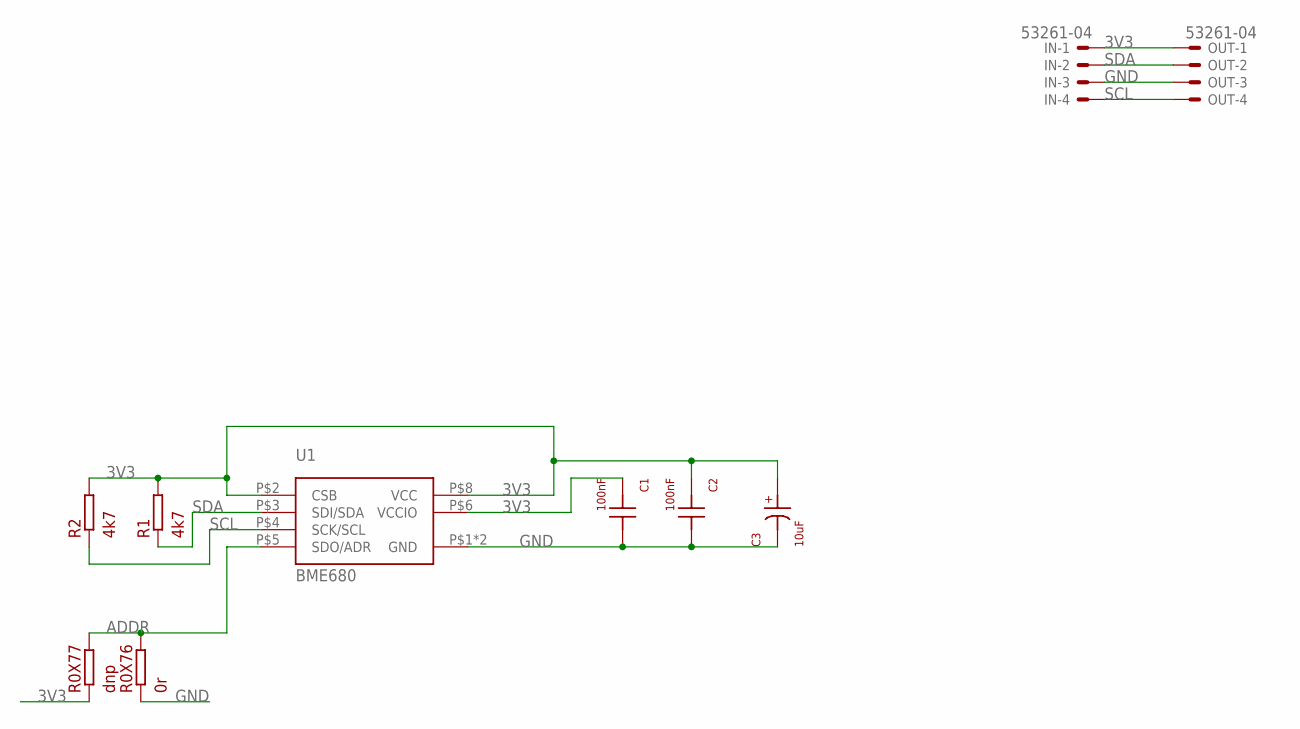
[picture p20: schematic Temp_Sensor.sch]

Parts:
C1, C2: 100nF; SMD_0402
C3: 10uF; CAP_POL_1206
IN: 53261-04
OUT: 53261-04
R0X76: 0r; SMD_0402
R0X77: dnp; SMD_0402
R1, R2: 4k7; SMD_0402
U1: BME680; BOSCH_LGA8

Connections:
3V3: C1.P$1, C2.P$1, C3.P, IN.1, OUT.1, R0X77.P$1, R1.P$2, R2.P$2, U1.P$2 (CSB), U1.P$6 (VCCIO), U1.P$8 (VCC)
ADDR: R0X76.P$2, R0X77.P$2, U1.P$5 (SDO/ADR)
GND: C1.P$2, C2.P$2, C3.N, IN.3, OUT.3, R0X76.P$1, U1.P$1 (GND), U1.P$7 (GND)
SCL: IN.4, OUT.4, R2.P$1, U1.P$4 (SCK/SCL)
SDA: IN.2, OUT.2, R1.P$1, U1.P$3 (SDI/SDA)

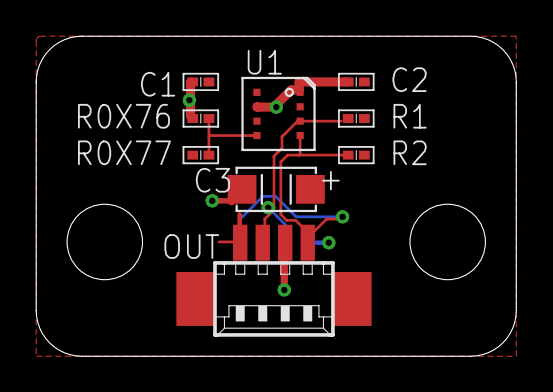
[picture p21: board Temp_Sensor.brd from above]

Board: 2 copper layers, 26.7 x 17.8 mm, 10 parts (1 on the bottom side), 5 nets.

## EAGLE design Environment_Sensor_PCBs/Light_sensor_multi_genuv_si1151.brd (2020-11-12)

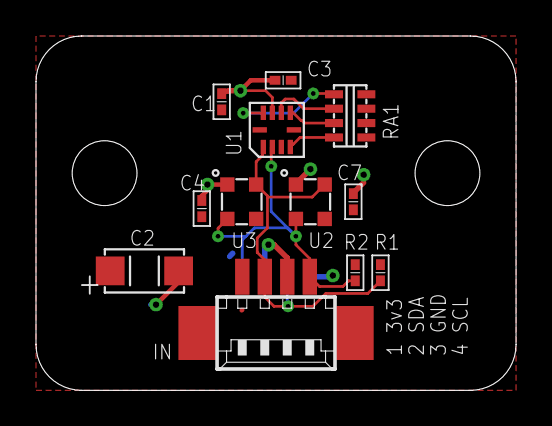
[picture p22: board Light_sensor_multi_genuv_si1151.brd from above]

Board: 2 copper layers, 26.7 x 19.7 mm, 13 parts (1 on the bottom side), 8 nets.

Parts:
C1, C3, C4, C7: 0.1uF; SMD_0402
C2: 10uF; CAP_POL_1206
IN: 53261-04
OUT: 53261-04
R1, R2: 1k8; SMD_0402
RA1: 47k; SMD_4X_0603
U1: SI115X_I2C_LIGHT_SENSOR_PROX_GM; QFN10
U2: GUVA_C32SM; 2X2.3OLGA
U3: GUVb_C31SM; 2X2.3OLGA

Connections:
3V3: C1.P$1, C2.P, C3.P$2, C4.P$2, C7.P$2, IN.1, OUT.1, R1.P$2, R2.P$2, RA1.5, RA1.6, RA1.7, RA1.8, U1.P$3, U2.P$4, U3.P$4
GND: C1.P$2, C2.N, C3.P$1, C4.P$1, C7.P$1, IN.3, OUT.3, U1.P$8, U2.P$1, U3.P$1
unnamed: RA1.1, U1.P$9
unnamed: RA1.3, U1.P$6
unnamed: RA1.2, U1.P$7
unnamed: RA1.4, U1.P$4
SCL: IN.4, OUT.4, R2.P$1, U1.P$2, U2.P$3, U3.P$3
SDA: IN.2, OUT.2, R1.P$1, U1.P$1, U2.P$2, U3.P$2

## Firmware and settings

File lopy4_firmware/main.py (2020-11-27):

# Original library was from https://github.com/ThingType/HPMA115S0_Python_library but intended for Raspberry Pi
# Modifying to work with Pycom Lopy4

#BME680 project from Micropython.. may need some modifications to run
import nets  #used by Wifi interface
import machine
import bme680 #used for BME680 sensor code
from i2c import I2CAdapter #used by BME680 and other I2C sensors
from network import LoRa #used to publish data on the LoRa network
import socket #used for various WiFi and Lora connections
import ubinascii #Used to pack/unpack byte segments for sending data to LoRa
import struct #Used to pack/unpack byte segments for sending data to LoRa
import time #used for sleep commands
import utime #used for timing commands
import os
import math
import lorakeys #store the active LoRa private keys to send data to TheThingsNetwork
import pycom #Used to publish data to PyBytes thru Send_Signal
import ustruct #Used to pack/unpack byte segments for sending data to LoRa
import si1132
from machine import UART, I2C,Pin #enable the I2C bus
adc = machine.ADC()             # create an ADC object
adc.init(bits=12)
apin = adc.channel(pin='P13',attn=3)   # create an analog pin on P13 to measure incoming battery voltage thru a 2Mohm / 178kohm divider network, scaling 40v to 3.3v

pycom.heartbeat(False) #needs to be disabled for LED functions to work
pycom.rgbled(0x7f0000) #red

def getBattery():
  Batt=0
  i=0
  while (i<20):#take 20 readings and average it to get a more consistent value
    val = apin()*0.01278#calculated based on testing.  Voltage divider with 2Mohm resistor on high side and 178kohm with a parallelled 100nF cap on low side
    #this scales the 40v max input voltage down to 3.3v
    Batt+=val
    i+=1
  BattAverage=Batt/20.0
  print('Battery Voltage = ',BattAverage)
  return BattAverage

#get online using known nets if available
#Do this before working with anything else.. Because some code faults will kick you offline unless you're in range of the primary network in pybytes_config.json
#If that happens... set up a cellphone as a hotspot using the SAME credentials as the primary network in pybytes_config.json and reboot the sensors
#then when it gets back online, you can fix the code, push it and turn off the hotspot..
if machine.reset_cause() != machine.SOFT_RESET:
    from network import WLAN
    wl = WLAN()
    if not wl.isconnected():
      wl.mode(WLAN.STA)
      original_ssid = wl.ssid()
      original_auth = wl.auth()

      print("Scanning for known wifi nets")
      available_nets = wl.scan()
      netsisee = frozenset([e.ssid for e in available_nets])

      known_nets_names = frozenset([key for key in nets.known_nets])
      net_to_use = list(netsisee & known_nets_names)
      try:
        net_to_use = net_to_use[0]
        net_properties = nets.known_nets[net_to_use]
        pwd = net_properties['pwd']
        sec = [e.sec for e in available_nets if e.ssid == net_to_use][0]
        if 'wlan_config' in net_properties:
            wl.ifconfig(config=net_properties['wlan_config'])
        wl.connect(net_to_use, (sec, pwd), timeout=10000)
        while not wl.isconnected():
            machine.idle() # save power while waiting
        print("Connected to "+net_to_use+" with IP address:" + wl.ifconfig()[0])
        pybytes.reconnect()

      except Exception as e:
        print("Failed to connect to any known network, going into AP mode")
        wl.init(mode=WLAN.AP, ssid=original_ssid, auth=original_auth, channel=6, antenna=WLAN.INT_ANT)
        
        
        
#added in code to make this code base work across all active assembles irregardless of which sensors are built in
HasSi1132=False #disable all inactive codes and activate the ones detected.
HasBME680=False
HasSi1151=False
HasGUVA=False
HasGUVB=False
HasVEML6075=False


i2c = I2C(0, pins=("P9","P10"))
i2c.init(I2C.MASTER, baudrate=100000)
activesensors=i2c.scan()#Scan for active I2C devices and store in a tuple
print(activesensors)#display the tuple of active sensors reported
pybytes.send_signal(2,len(activesensors))
if len(activesensors)>0:#see if any devices were detected.
  for c in range (0,len(activesensors)):#enable code for any found sensors
    pybytes.send_signal(2,activesensors[c])#publish detected sensors to Pybytes for remote diagnostics
    time.sleep(1)#have to sleep 1s between each pybytes.send_signal
    if activesensors[c]==118:#0x60 IE bme680 - Sensor works but some boards may need calibration/ burn in to correct stuck VOC resistance.
      HasBME680=True
    if activesensors[c]==96:#0x60 IE Si1132 - Sensor marked EOL but may exist in some assemblies.  Code works but needs fine-tuning to work properly between low and high intensity
      HasSi1132=True
    if activesensors[c]==83:#0x60 IE Si1151 - Currently active sensor.  Note some old sensors may have wrong address 
      HasSi1151=True
    if activesensors[c]==81:#0x60 IE Si1151 - Currently active sensor.  Note some old sensors may have wrong address due to manufacturing defect.  They still work.
      HasSi1151wa=True# this is a rare batch of parts that has the wrong i2c address
    if activesensors[c]==56:#0x60 IE GenUV Sensor for UV-A - Small batch of sensors were assembled - the chip costs $45 in low quantities
      HasGUVA=True
    if activesensors[c]==57:#0x60 IE GenUV Sensor for UV-B - Small batch of sensors were assembled - the chip costs $45 in low quantities
      HasGUVB=True
    if activesensors[c]==20:#0x10 7 bit slave address per datasheet - sensor discontinued but may exist in some assemblies
      HasVEML6075=True
    if activesensors[c]==112:#0x38 7 bit slave address per datasheet - sensor discontinued but may exist in some assemblies
      HasVEML6070=True
    elif activesensors[c]==45:# not used yet.
      sensors2=True
    
    
  
i2c_dev = I2CAdapter()
if HasBME680 == True:
  sensor = bme680.BME680(i2c_device=i2c_dev)
if HasSi1132 == True:
  si = si1132.SI1132(i2c_dev)

#Older dust sensors have a 2 year life unless the fan is cycled on/off between readings. 
#These older sensors also don't respond to commands that would activate the fan properly,
#So I added a MOSFET to switch the fan power remotely to put it into low power mode.
#Typical power consumption is 80mA for the sensor alone.. so cutting the sensor off saves A LOT of power
DUSTEN = Pin('P23', mode=Pin.OUT)
PinOn=1
PinOff=0
print("turning fan off")
DUSTEN.value(PinOff)




# Initialise LoRa in LORAWAN mode.
# Please pick the region that matches where you are using the device:
# Asia = LoRa.AS923
# Australia = LoRa.AU915
# Europe = LoRa.EU868
# United States = LoRa.US915
#lora = LoRa(mode=LoRa.LORAWAN, region=LoRa.US915)

#Above code bypassed because I needed to manually select the correct frequencies to work properly in the US.
#Otherwise, it wanted to send to 64 channels randomly and 88% would be to inactive channels for that region
print('Initialize LoRa')
lora = LoRa(mode=LoRa.LORAWAN, public=1,  adr=0, tx_retries=0)
print('Remove default channels')
for i in range(0, 71):
    lora.remove_channel(i)
print('Removed default channels')
time.sleep(1)
    
    # Set US ISM 915 channel plan for TTN US
lora.add_channel(0, frequency=903900000, dr_min=0, dr_max=3)
lora.add_channel(1, frequency=904100000, dr_min=0, dr_max=3)
lora.add_channel(2, frequency=904300000, dr_min=0, dr_max=3)
lora.add_channel(3, frequency=904500000, dr_min=0, dr_max=3)
lora.add_channel(4, frequency=904700000, dr_min=0, dr_max=3)
lora.add_channel(5, frequency=904900000, dr_min=0, dr_max=3)
lora.add_channel(6, frequency=905100000, dr_min=0, dr_max=3)
lora.add_channel(7, frequency=905300000, dr_min=0, dr_max=3)


print('US channels set')
time.sleep(1)
lora.nvram_restore()
#getBattery() #I was hoping to pass battery voltage up to TTN, but it's not yet implemented, so bypass for now.
if not lora.has_joined():
  pybytes.send_signal(2,4)
  print('Joining LoRa via OTAA')

# join a network using ABP (Activation By Personalization)  This was highly problematic because when the sensor lost power, the sent counter would reset and no data would get thru
#lora.join(activation=LoRa.ABP, auth=(dev_addr, nwk_swkey, app_swkey))
# join a network using OTAA (Over the Air Activation)
  lora.join(activation=LoRa.OTAA, auth=(lorakeys._dev_eui,lorakeys._app_eui, lorakeys._app_key), timeout=0, dr=0)
else:
  print('LoRa already joined..')
  pybytes.send_signal(2,3)
  time.sleep(0.4)
  pycom.rgbled(0x007f00) #grn    
  time.sleep(0.1)
  pycom.rgbled(0x000000) #blk    
  time.sleep(0.4)
  pycom.rgbled(0x007f00) #grn    
  time.sleep(0.1)
  pycom.rgbled(0x000000) #blk    
  time.sleep(0.4)
  pycom.rgbled(0x007f00) #grn    
  time.sleep(0.1)
  pycom.rgbled(0x000000) #blk    
  
#currently, this waits to join a channel.. but if no LoRa devices are available, it would stick here forever
#I want to eventually set this up so it checks for WIFI first.. and sends direct to AWS.. If Wifi isn't available, fallback to LoRa
# wait until the module has joined the network
while not lora.has_joined():
    time.sleep(2.4)
    pycom.rgbled(0x7f7f00) #ylw    
    time.sleep(0.1)
    pycom.rgbled(0x000000) #blk    
    print('Not yet joined...')
    pass
# create a LoRa socket
s = socket.socket(socket.AF_LORA, socket.SOCK_RAW)

# set the LoRaWAN data rate
s.setsockopt(socket.SOL_LORA, socket.SO_DR, 3)






# initialize class for HPMA115S0 Honeywell Dust Particulate sensor
# sensor returns PM2.5 and PM10 particulate count in Parts Per Billion
# across serial UART at 9600, 8,N,1
#hpma115S0 = HPMA115S0()
uart = UART(1, 9600)                         # init with given baudrate
uart.init(9600, bits=8, parity=None, stop=1) # init with given parameters
read_timeout=2000
MSG_CHAR_1 = b'\x42' # First character to be recieved in a valid packet
MSG_CHAR_2 = b'\x4d' # Second character to be recieved in a valid packet
# datasheet https://sensing.honeywell.com/honeywell-sensing-particulate-hpm-series-datasheet-32322550
# Recommended to prolong sensor (Fan) life to shut off sensor fan (send Stop measurements CMD) between readings
# when ready to read, send start measurement command, wait at least 6 seconds, then Read measurement command.
# When sensor intially starts, it auto-writes a 32 byte string with these values embedded once per second.. 
# you have to send stop auto send command to disable this.

#send a status to Pybytes that we made it past the first few states (IE LoRa)
pybytes.send_signal(2,0)
#BME680 project from Micropython.. written for Pycom Wipy but doesn't utilize the proprietary module to manage/convert the VOC data
#Init the BME680
# These oversampling settings can be tweaked to
# change the balance between accuracy and noise in
# the data.
if HasBME680 == True:

  try:
   sensor.set_humidity_oversample(bme680.OS_2X)
   sensor.set_pressure_oversample(bme680.OS_4X)
   sensor.set_temperature_oversample(bme680.OS_8X)
   sensor.set_filter(bme680.FILTER_SIZE_3)
  except Exception as e:
   print('DEBUG :: @init the BME680 :: Exception: ' + str(e))
   pycom.rgbled(red)
   machine.idle()



print("Starting")
#send a status update to Pybytes that we're about to start the Loop
pybytes.send_signal(2,1)

while 1:
  print("Looping")
  DUSTEN.value(PinOn)
  print("turning fan on")
  #hpma115S0.startParticleMeasurement()#Wake up the HOneywell dust sensor
  time.sleep(6)#Give Honeywell sensor 6 seconds for readings to normalize
  inp='' #zero out the input buffer
  recv=[]#zero out the receive tuple
  dump=uart.read()#zero out the receive buffer
  start=utime.ticks_ms()#set up a start point for sensor timeout
  pm10=ustruct.pack('>H',int(0))#put some null values in these registers in case there's no HPMA sensor found
  pm25=ustruct.pack('>H',int(0))
  pm1=ustruct.pack('>H',int(0))
  pm4=ustruct.pack('>H',int(0))
  while(utime.ticks_diff(start,utime.ticks_ms())> -read_timeout):
    if(uart.any()>0):
      inp = uart.read(1) # Read a character from the input
    #print('char received=',inp)
    if inp == MSG_CHAR_1: # check it matches
      #print('first match')
      recv += inp # if it does add it to recieve string
      if(uart.any()>0):
        inp = uart.read(1) # read the next character
      if inp == MSG_CHAR_2: # check it's what's expected
        #print('second match')
        recv += inp # att it to the recieve string
        recv += uart.read(30) # read the remaining 30 bytes
        calc = 0
        ord_arr = []
        for c in bytearray(recv[:-2]): #Add all the bytes together except the checksum bytes
          calc += c
          ord_arr.append(c)
        # self.logger.debug(str(ord_arr))
        sent = (recv[-2] << 8) | recv[-1] # Combine the 2 bytes together
        if sent == calc: 
          print('recv=',recv)
          checkforcompact=recv[4]+recv[5]+recv[10]+recv[11]#the Compact version of the HPMA115 has additional pm1 and pm4 values..Add these bytes together
          #but the stupid thing is, they rearrange the byte locations rather than use unused bytes in the old 32 byte packet
          #this is infuriating since there's no legitimate way to differentiate the sensors in code EXCEPT hope that there should never be ZERO for any of the particulate values
          if checkforcompact==0:#If the bytes you added together are all zero, then we MOST LIKELY have the old non-compact sensor. *fingerscrossed*
            pm10=ustruct.pack('>H',int((recv[6]*256)+recv[7]))
            pm25=ustruct.pack('>H',int((recv[8]*256)+recv[9]))
          else:
            pm1=ustruct.pack('>H',int((recv[4]*256)+recv[5]))
            pm25=ustruct.pack('>H',int((recv[6]*256)+recv[7]))
            pm4=ustruct.pack('>H',int((recv[8]*256)+recv[9]))
            pm10=ustruct.pack('>H',int((recv[10]*256)+recv[11]))
          break
        else:
          print('recv=',recv)#we failed the checksum, so publish some diagnostic data for troubleshooting
          print('checksum fail',sent,'!=',calc)
      else:
        print('second char mismatch =',inp)# first character matched but second didn't..  This should never happen?

  DUSTEN.value(PinOff)
  print("turning fan off")

   
#BME680 project from Micropython.. may need some modifications to run.. Actually, looks like it was written for Pycom Wipy
  tempstruct=ustruct.pack('>H',int(0))#lets start by zeroing out the structs used to send to LoRa in case the sensor isn't found, we can still publish everything else
  dewstruct=ustruct.pack('>H',int(0))
  pressstruct=ustruct.pack('>H',int(0))
  relhumidstruct=ustruct.pack('>H',int(0))
  vocStruct=ustruct.pack('>L',int(0))

  if HasBME680 == True:#if the BME was detected, get some data.

    try:
      #while True:
      if sensor.get_sensor_data():

        output = "{} C, {} hPa, {} RH, {} RES,".format(
          sensor.data.temperature,
          sensor.data.pressure,
          sensor.data.humidity,
          sensor.data.gas_resistance)

        print(output)
        tempstruct=ustruct.pack('>H',int(sensor.data.temperature))
        dewstruct=ustruct.pack('>H',int(sensor.data.dew_point))
        pressstruct=ustruct.pack('>H',int(sensor.data.pressure))
        print('pressure:',pressstruct[0]*256+pressstruct[1])
        relhumidstruct=ustruct.pack('>H',int(sensor.data.humidity))
        vocStruct=ustruct.pack('>L',int(sensor.data.gas_resistance))

    except Exception as e:
      print('DEBUG :: @Get Reading from the BME680 :: Exception: ' + str(e))#oops, something went wrong,, publish some diagnostic data to troubleshoot
      pass
    
#let's look for some light sensor data
#but first, let's zero out the placeholders
  broadlum=0
  IR=0
  if HasSi1132 == True:

    try:
      broadlum=round(si.read_visible())
      broadlumstruct=struct.pack(">h",broadlum)
    except Exception as e:
      print('DEBUG :: @Get Reading from the si1132 :: Exception: ' + str(e))
      pass
    try:
      IR=round(si.read_IR())
      IRlumstruct=struct.pack(">h",IR)
    except Exception as e:
      print('DEBUG :: @Get Reading from the si1132 :: Exception: ' + str(e))
      pass
  broadlumstruct=struct.pack(">h",broadlum)
  IRlumstruct=struct.pack(">h",IR)
  Battery=getBattery() #measure the input voltage on P13
  BattStruct=ustruct.pack('>H',int(Battery*10))#use an int instead of a float with 1 decimal accuracy, on TTN packet decoder this gets divided by 10

  s.setblocking(True)
  print("Sending data!")
  s.send(bytes([pm25[0],pm25[1],pm10[0],pm10[1],#Particulate values for pm2.5 and pm10
                 tempstruct[0],tempstruct[1],#Temperature
                 relhumidstruct[0],relhumidstruct[1],#Relative Humidity
                 dewstruct[0],dewstruct[1],#dewpoint
                 pressstruct[0],pressstruct[1],#Barometric Pressure
                 0x00,0x00,#This is a placeholder for UV data from the Si1133
                 broadlumstruct[0],broadlumstruct[1],
                 IRlumstruct[0],IRlumstruct[1],
                 vocStruct[0],vocStruct[1],vocStruct[2],vocStruct[3],#VOC Resistance
                 pm1[0],pm1[1],pm4[0],pm4[1],#particulate values for pm1 and pm4
                 BattStruct[0],BattStruct[1]#Battery Voltage
               ]))
   
#Publish duplicate data to Pybytes.. Have to put a 1s delay between each packet or it will reject them.. Them's the Pybytes rules, not mine!
  pybytes.send_signal(0,(pm25[0]*256)+pm25[1])
  time.sleep(1)
  pybytes.send_signal(1,(pm10[0]*256)+pm10[1])
  time.sleep(1)
  pybytes.send_signal(3,sensor.data.gas_resistance)#This is frustrating as frig... Pybytes treats this as a Signed Long not an Unsigned Long.. So the data looks wierd sometimes if the value is high IE > 0xF000 0000
  time.sleep(1)
  pybytes.send_signal(4,int(sensor.data.temperature))
  time.sleep(1)
  pybytes.send_signal(5,int(sensor.data.humidity))
  time.sleep(1)
  pybytes.send_signal(6,int(sensor.data.dew_point))
  time.sleep(1)
  pybytes.send_signal(7,int(sensor.data.pressure*0.2952998307)/10)#this is frustrating as well.. pybytes takes this in as a float and blows the decimal to kingdom come.. it should be a 0.1 InHg value but pybytes displays it to 10 places..
  time.sleep(1)
  pybytes.send_signal(8,broadlum)
  time.sleep(1)
  pybytes.send_signal(10,IR)
  time.sleep(1)
  pybytes.send_signal(11,(pm1[0]*256)+pm1[1])
  time.sleep(1)
  pybytes.send_signal(12,(pm4[0]*256)+pm4[1])
  time.sleep(1)
  pybytes.send_signal(13,Battery)
 
  print('saving LoRa NVRAM')
  lora.nvram_save()
    # make the socket non-blocking
    # (because if there's no data received it will block forever...)
  s.setblocking(False)
  print("receiving data!")
    # get any data received (if any...)
  data = s.recv(64)
  print(data)
  time.sleep(300)#wait 5 minutes before next reading

 

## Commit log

2019-06-16 Current release of boards
    These are the boards files used in the initial 1o sensor prototypes, plus the full BOM
    [10units_buy.ods, Control_Board.brd, Control_Board.sch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]
2019-06-16 Uploaded schematic files for existing builds
2019-06-25 initial firmware to read HPMA115S0 dust sensor - nonfunctional as of yet
2019-06-25 Create bme680.py
    Created library place holder for BME680 sensor code
2019-06-25 Create si11xx.py
    Created library placeholder for si1132 and si1151 digital ambient light sensors
2019-06-25 Update bme680.py
    Link to Adafruit Micropython code sample for the BME680
2019-06-26 Update si11xx.py
    Adding sample code from Silabs AN498 Application Note
2019-06-26 Create i2c.py
    Copied code from another Pycom project
2019-06-28 Update bme680.py
    smbus declaration was for RasPi python.. changed to Pycom-standard i2c initialization
2019-10-21 Test sample code for HPMA sensor
    Testing with start/stop functionality for sensor longevity
    Output:
    waking up HPMA
    b'\xa5\xa5'
    disable Autosend
    b'\xa5\xa5'
    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
2019-12-18 Current 3d printed housing design
    These parts are printed using white PETG, 0.4mm nozzle and .3mm layer height, upside down with no supports.
    [Base_pycom.v3.stl, Louver_HPMA.v2.stl, Louver_L4_v2.stl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]
2020-03-13 Adding code to talk to the si1132 sensor
    Some of the boards have si1132 IR/Ambient sensors, this code will talk with them.
2020-03-13 Added module to talk to the si1132 sensor
    This module communicates with the sensor, and only a few code additions needed in main.py to connect
2020-06-10 Created a patch to control dust sensor power
    This adapter board fits between the main board and the Pycom module, and allows you to power cycle the dust sensor by turning p23 high(On) or low(Off). It helps since the Honeywell HPMA115S0 dust sensor sometimes gets stuck in Lala land and won't respond to commands. Also, allows us to completely shut off the sensor, reducing power demand by 80ma when it's running or 20ma when the fan is off. Include PDF Schematic, Eagle files and the Gerbers sent to OSHPARK.
    [BOM_dust-sensor-bypass-adapter.xlsx, Dust_Sensor_Bypass_adapter.brd, Dust_Sensor_Bypass_adapter.sch]
2020-08-06 Update main.py
    Added some code to detect when I2C sensors were connected and skip over code that referred to disconnected sensors. It's not perfect yet but seems to allow the same code to work in a few places.
    [main.py]
2020-10-16 Update main.py
    Merged the code I had working on new and old sensor platforms to support both from the same base code.
2020-10-18 Update main.py
    Verified and added the address for the si1151 parts that have the wrong i2c address burned in from the factory
    [main.py]
2020-10-20 Update main.py
    VOCStruct initialized as Int instead of Long - causes crash when BME680 not reporting properly.
    [main.py]
2020-10-26 Update README.md
    Switched devices to Pycom LoPy4
2020-11-04 Adding battery measurement capability
    Added a voltage divider to P13 to measure input voltage, so we can remotely monitor/diagnose solar charging status. Devices that don't have the divider will simply read 0v and can be retrofitted with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
2020-11-05 Update main.py
    Added ADC initialization for battery voltage
2020-11-12 Adding most recent boards
    [Light_sensor_multi_genuv_si1151.brd, hpma115c0-004_adapter.brd, hpma115c0-004_adapter.sch]
2020-11-12 Creating separate folders for each PCB
    This folder will house the Control Board design filse
2020-11-12 Rename Environment_Sensor_PCBs/Control_Board.brd to Environment_Sensor_PCBs/Control_Board/Control_Board.brd
    Moving to a separate folder
    [Control_Board.brd]
2020-11-18 Update main.py
    Improved boot process by properly restoring LoRa nvram before join process. If it's already joined, it can skip the join process, wasting less time before beginning measurements
    [main.py]
2020-11-25 Update main.py
    Revised battery voltage calculation
2020-11-27 Update main.py
    added more debug notes to trace down failures, sped up wifi connection when primary AP already connected on start
    [main.py]
2021-03-03 Create boot.py
    Adding Bluetooth deinit process to reduce power consumption some
